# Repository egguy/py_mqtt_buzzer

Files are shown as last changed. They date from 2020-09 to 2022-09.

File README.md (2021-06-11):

# Push my button

Doc sur le jeu où il faut slapper le plus rapidement possible un bouton

## Principe

$x joueur s'affrontent et doivent appuyer sur un bouton le plus vite possible

Suite à un appui, allumage du premier bouton appuyé, verrouillage des autres.

Quand un bouton est appuyé une variable globale empeche les autres boutons de se déclancher et le buzzer correspondant s'allume. L'envoi d'un reset (ou appui sur le reset), remet à 0 la variable, et coupe les lumiéres.

Le verrouillage d'un bouton individuel est permanent jusqu'a l'envoi d'un deverouillage. L'allumage du buzzer par MQTT est independant de son état.

Envoi des events en MQTT

## composants:

* Un ESP32 en micropython
* $x joueur
* $x input (boutons)
* $x out (pupitre)
* $x out pour boutons

# Mapping

```python
# An array of player led pin ex array pos 0 -> player 1 -> pin 13
PLAYERS_LED_PIN = [13, 12, 14, 27]
# input
PLAYERS_BUZZER_PIN = [25, 33, 32, 35]
# buzzer lights
PLAYERS_BUZZER_LED_PIN = [5, 17, 16, 4]
# Reset on 34
```

# Install

Download micropython ESP32 v 1.13 min
Upload on the board with esptools

upload on the board:
* primitives/
* config.py
* mqtt_as.py
* players.py
* main.py
* config.json

## config.json file

```json
{
  "server": "<server_ip_dns>",
  "ssid": "<wifi_ssid>",
  "wifi_pw": "<wifi_pass>",
  "user": "<mqtt_user>",
  "password": "<mqtt_password>"
}
```
### Update the connection from the serial

Start with a Ctrl-C to stop the current process

then send line by line:

exemple:
```python
f = open('config.json', 'w')
f.write("""{
  "server": "<server_ip_dns>",
  "ssid": "<wifi_ssid>",
  "wifi_pw": "<wifi_pass>",
  "user": "<mqtt_user>",
  "password": "<mqtt_password>"
}""")
f.close()
```

then do a ctrl-d to soft restart the system.

# Protocol

Use MQTT protocol and broker

## topics + messages

* buzz/ping
  * every 10s send serial
* buzz/{serial}/events -> events sent by the buzzer controller
  * 0 -> 3: buzzer number pressed
  * r: reset pressed
* buzz/{serial}/config -> send config to the buzzer
  * reset -> reset the buzzer (all light off, allow a new press)
  * on $i -> set player $i buzzer light on
  * off $i -> turn of player $i led
  * lock -> prevent press
  * lock $i -> prevent player press (disable buzzer, don't touch the state of the light)
  * unlock -> unlock
  * unlock $i -> unlock as player (don't touch the state of the light)

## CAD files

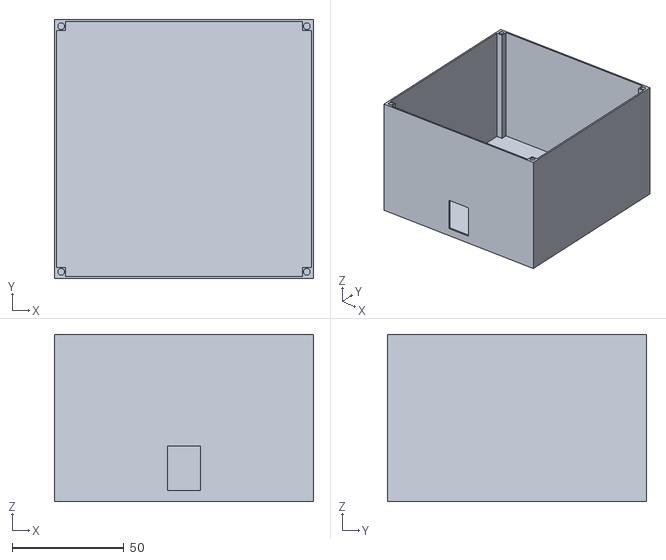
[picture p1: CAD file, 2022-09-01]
3d_models/box.stl
116.0 x 116.0 x 75.0

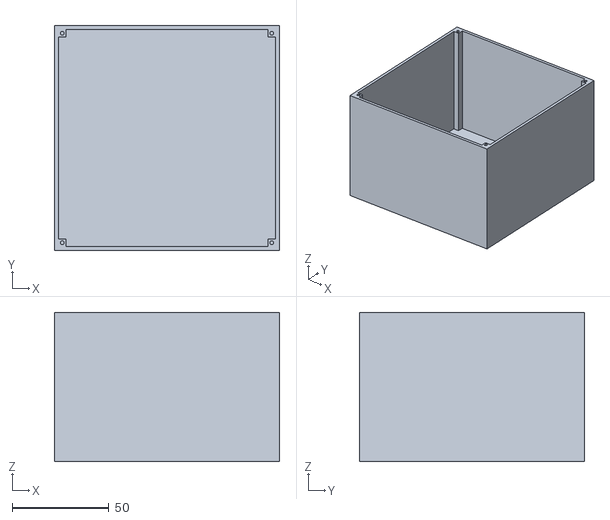
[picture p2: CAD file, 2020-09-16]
3d_models/STL/boitier_v2.stl
116.0 x 116.0 x 77.0

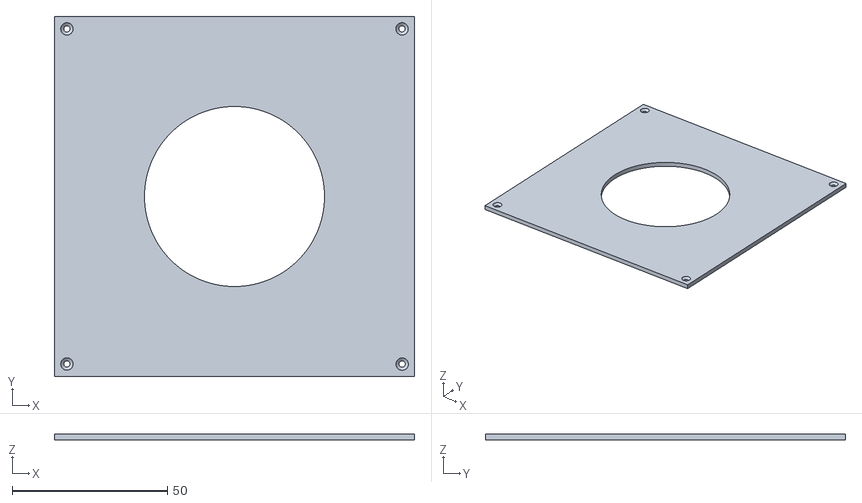
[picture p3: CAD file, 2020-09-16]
3d_models/STL/couvercle.stl
116.0 x 116.0 x 2.00

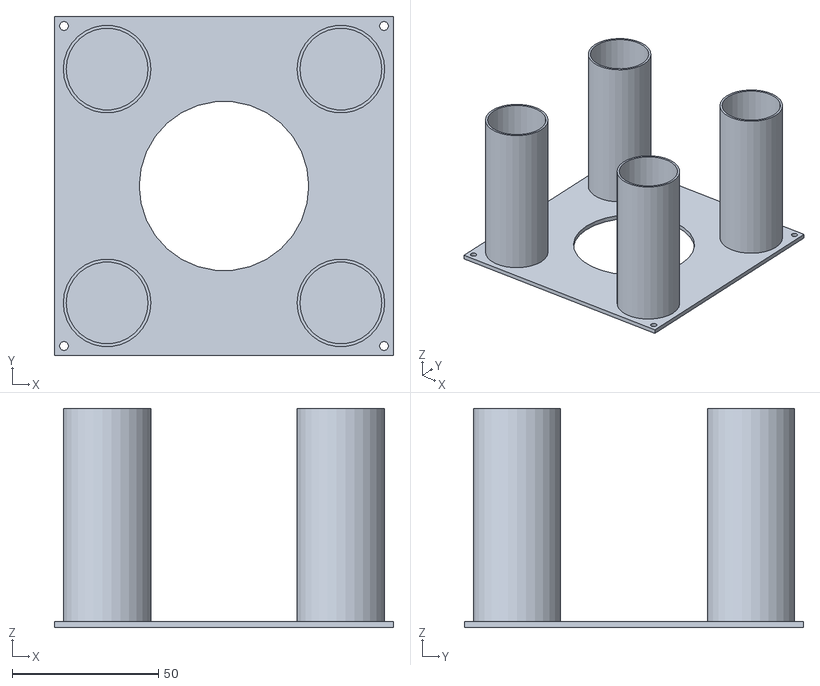
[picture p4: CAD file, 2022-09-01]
3d_models/top.stl
116.0 x 116.0 x 75.0

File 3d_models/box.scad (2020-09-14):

$fn=100;
diam_button = 58;

plate = diam_button * 2;
heigth = 75;
wall_thickness =  2;
screw_hole_diam = 3;

module keystone(){
    rotate([0,-90,-90]){
        cube([20,15,wall_thickness]);
    }
}

module box(){
    inside_box = plate - wall_thickness;
    translate([plate/2, plate/2, heigth/2]){
    difference(){
        cube([plate, plate, heigth], center=true);
        translate([0, 0, wall_thickness/2]){
        cube([inside_box, inside_box, heigth-wall_thickness], center=true);
        }
    }
}
}

module screw_hole(diam, offset=1){
    center = diam + offset;
    difference(){
        square(center);
        translate([center/2, center/2, 0]){
            circle(diam/2);
        }
    }
}

module screw_3d(){
    linear_extrude(heigth){
        screw_hole(screw_hole_diam);
    }
}




difference(){
    box();
    translate([(plate-15)/2, 0, 5]){
        keystone();
    }
}

wall_trans = wall_thickness/2;
move = screw_hole_diam+1;

translate([wall_trans, wall_trans, 0]){
    screw_3d();
}
translate([plate-wall_trans-move, wall_trans, 0]){
    screw_3d();
}
translate([wall_trans, plate-wall_trans-move, 0]){
    screw_3d();
}
translate([plate-wall_trans-move, plate-wall_trans-move, 0]){
    screw_3d();
}

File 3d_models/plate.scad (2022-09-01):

$fn=30;
diam_button = 58;
wall_thickness = 2;
screw_diam = 3;
offset = 1;
heigth = 75;

support_lenght = 30;

plate = diam_button * 2;

/*
module support() {
    linear_extrude(heigth){
        translate([support_lenght/2, 0]){
            square([wall_thickness, support_lenght]);
            translate([support_lenght/2,support_lenght/2, 0]){
                rotate(90){
                    square([wall_thickness, support_lenght]);
                }
            }
    
    }
}

}
*/
module support() {
    linear_extrude(heigth){
        translate([support_lenght/2, support_lenght/2]){
            difference(){
                circle(support_lenght/2);
                circle((support_lenght/2)-1);
            }
        }
    }
}

module base_top_plate() {
difference(){
    square(plate);
    translate([plate/2, plate/2, 0]){
        circle(diam_button/2);
    }
}
}


module top_plate(){
    hole_diameter = screw_diam / 2;
    move = wall_thickness/2+(hole_diameter+offset)/2+offset;
    difference(){
        base_top_plate();
        translate([move, move, 0]){
            circle(hole_diameter);
        }
        translate([move, plate-move, 0]){
            circle(hole_diameter);
        }
        translate([plate-move, move, 0]){
            circle(hole_diameter);
        }
        translate([plate-move, plate-move, 0]){
            circle(hole_diameter);
        }
    }
}

linear_extrude(2){
    top_plate();
}

margin = 1;

// 1 st Bottome Left
translate([
    wall_thickness+margin,
    wall_thickness+margin
]){
    support();
}

// 2nd - Bottom Right
translate([
    plate-wall_thickness-support_lenght-margin,
    wall_thickness+margin
]){
    support();
}

// 3rd Up Left
translate([
    wall_thickness+margin,
    plate-wall_thickness-support_lenght-margin
]){
    support();
}

// Up right
translate([
    plate-wall_thickness-support_lenght-margin,
    plate-wall_thickness-support_lenght-margin
]){
    support();
}

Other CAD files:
3d_models/buzzer boitier v4.f3d

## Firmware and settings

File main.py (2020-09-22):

import uasyncio as asyncio
from primitives.queue import Queue
from primitives.pushbutton import Pushbutton
from players import *
from config import config, serial
# MQTT Section
from mqtt_as import MQTTClient

# game mode
NORMAL = const(1)
VERSUS = const(2)

config_topic = "buzz/{}/config".format(serial)
event_topic = "buzz/{}/events".format(serial)
announce_topic = "buzz/ping"

ping = False
locked = False
# queue to push message to mqtt
notification_queue = Queue(maxsize=16)
# Reset pin
reset_pin = Pin(19, Pin.IN, Pin.PULL_UP)


def button_press(pos: int) -> None:
    """
    Handler for button press
    """
    global locked  # Prevent creating local variable
    if locked:
        print("locked no press")
        return
    if players_lock[pos]:
        print("Player lock")
        return
    # Lock button press
    locked = True
    # light matching player
    light_player(pos)
    # Push player number in mqtt
    notification_queue.put_nowait(pos)


def reset_state():
    """
    Reset the buttons light and allow another press
    """
    global locked  # Prevent creating local variable
    locked = False
    reset_lights()


def reset():
    reset_state()
    # send reset message
    notification_queue.put_nowait("r")


pb_reset = Pushbutton(reset_pin)
pb_reset.press_func(reset)

# Instanciate and attach button to the asyncio button manager
for i, button in enumerate(players_buzzer):
    pb = Pushbutton(button, suppress=True)
    pb.press_func(button_press, (i,))


def receive_callback(topic: bytes, msg: bytes, retained):
    global locked
    print((topic, msg, retained))
    if msg == b'reset':
        reset_state()
    elif msg.startswith(b'on') and len(msg) == 4:
        player = msg[3] - 48  # 48 = char '0'
        if 0 <= player < len(players_led):
            print("light ", player)
            light_player(player)
    elif msg.startswith(b'off') and len(msg) == 5:
        player = msg[4] - 48  # 48 = char '0'
        if 0 <= player < len(players_led):
            print("off", player)
            lightoff_player(player)
    elif msg.startswith(b'lock'):
        if len(msg) == 4:
            print("lock")
            locked = True
        elif len(msg) == 6:
            player = msg[5] - 48
            if 0 <= player < len(players_led):
                print("plock", player)
                players_lock[player] = 1
    elif msg.startswith(b'unlock'):
        if len(msg) == 6:
            print("unlock")
            locked = False
        elif len(msg) == 8:
            player = msg[7] - 48
            if 0 <= player < len(players_led):
                print("punlock", player)
                players_lock[player] = 0


async def conn_han(mqtt_client):
    global ping
    await client.subscribe(config_topic)
    if not ping:
        asyncio.create_task(ping_task(mqtt_client))


async def ping_task(mqtt_client):
    global ping
    ping = True
    while True:
        await mqtt_client.publish(announce_topic, serial, qos=1)
        await asyncio.sleep(10)


async def main(mqtt_client, queue: Queue):
    await mqtt_client.connect()

    while True:
        data = await queue.get()
        print('publish', data)
        # If WiFi is down the following will pause for the duration.
        await mqtt_client.publish('buzz/{}/events'.format(serial), '{}'.format(data), qos=1)


config['subs_cb'] = receive_callback
config['connect_coro'] = conn_han

MQTTClient.DEBUG = True  # Optional: print diagnostic messages
client = MQTTClient(config)
# loop = asyncio.get_event_loop()

print("Serial: {}".format(serial))

try:
    asyncio.run(main(client, notification_queue))
finally:
    client.close()  # Prevent LmacRxBlk:1 errors

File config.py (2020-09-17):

# config.py Local configuration for mqtt_as demo programs.
from sys import platform
from mqtt_as import config
import ujson
import machine
import ubinascii

with open("config.json") as fd:
    config.update(ujson.load(fd))

serial = ubinascii.hexlify(machine.unique_id()).decode('ascii')


# For demos ensure the same calling convention for LED's on all platforms.
# ESP8266 Feather Huzzah reference board has active low LED's on pins 0 and 2.
# ESP32 is assumed to have user supplied active low LED's on same pins.
# Call with blue_led(True) to light

"""
if platform == 'esp8266' or platform == 'esp32' or platform == 'esp32_LoBo':
    from machine import Pin
    def ledfunc(pin):
        pin = pin
        def func(v):
            pin(not v)  # Active low on ESP8266
        return func
    wifi_led = ledfunc(Pin(0, Pin.OUT, value = 0))  # Red LED for WiFi fail/not ready yet
    blue_led = ledfunc(Pin(2, Pin.OUT, value = 1))  # Message received
elif platform == 'pyboard':
    from pyb import LED
    def ledfunc(led, init):
        led = led
        led.on() if init else led.off()
        def func(v):
            led.on() if v else led.off()
        return func
    wifi_led = ledfunc(LED(1), 1)
    blue_led = ledfunc(LED(3), 0)

"""

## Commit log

2020-09-10 Add openSCAD generators
    [box.scad, plate.scad]
2020-09-14 Updated openSCAD models
    [box.scad, plate.scad]
2020-09-16 Added 3D model
    Add fusion 360 model + STL
    [boitier_v2.stl, buzzer boitier v4.f3d, couvercle.stl]
2020-09-17 Littles changes * Allow to reset buzzer from MQTT * Subscribe by uuid * ping module * less bootstrap code
    [maine.py]
2020-09-22 Update lib to manage LED (with ULN2003 use 0 for off and 1 for light) Updated readme
2022-09-01 Better alignment of the holes
    [box.stl, plate.scad, top.stl]
